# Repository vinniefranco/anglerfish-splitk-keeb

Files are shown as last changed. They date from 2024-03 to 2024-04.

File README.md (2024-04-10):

# Anglerfish Keyboard

Anglerfish, is a split keyboard with 3x5 column staggered keys, two thumb keys, and a trackpoint.

The Trackpoint can be placed on either side, and the PCB is a reversible design.

---

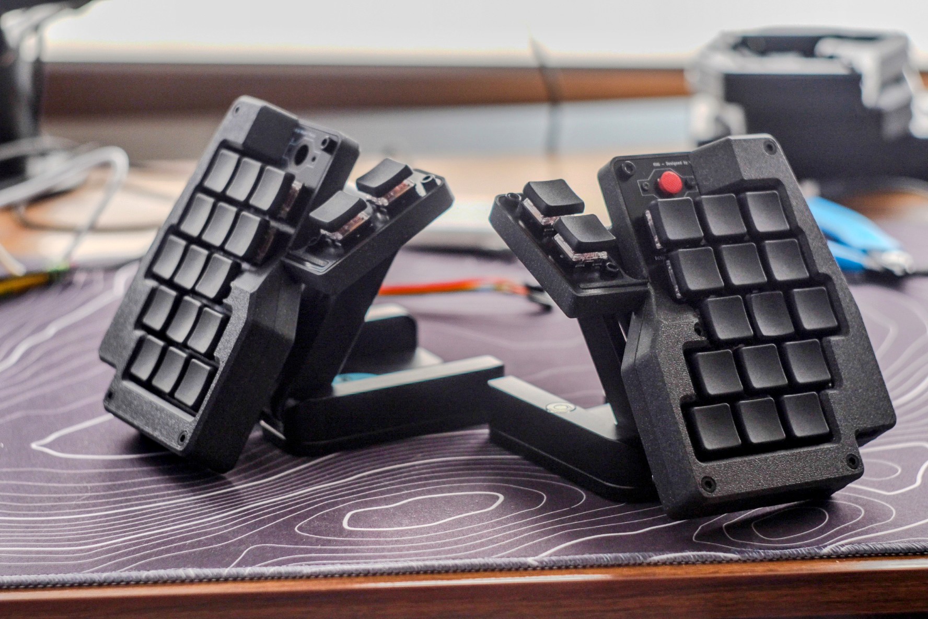
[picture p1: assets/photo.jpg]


---

### Models
You can find all the step files for the case [here](assets/models)

### Electronic Components 
[Build of materials](assets/bom.md)

### Default Firmware Keymap
Keymap

---

### Build Guide
Soon...

> [!NOTE]\
> IMPORTANT: When submitting the gerber for manufacturing, set the PCB thickness to 0.8mm.

> [!WARNING]\
>  Gotchas
> Trackpoint ZMK support is bleeding edge. Thar be dragons.

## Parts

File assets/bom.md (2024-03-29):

| Part name | Amount | Link
| --- | ---|  --- |
| M3 Brass Inserts | 20x | |
| 1/4" Brass Inserts | 2x |  |
| M3x10 Hex bolts | 4x | |
| M3x12 Hex bolts | 8x | |
| M3x6 Hex bolts | 6x | |
| M1.8 Torx bolts | 2x | [Aliexpress](https://www.aliexpress.us/item/3256802141626309.html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)  | 
| nice!nano or clone | 2x | [Aliexpress](https://www.aliexpress.us/item/3256805848952479.html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)
| Diodes - 1N4148W - SOD-123 | 32x | [Aliexpress](https://www.aliexpress.us/item/3256806388498396.html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)
| Reset Button - B35-1000 - SPST | 2x | [Aliexpress](https://www.aliexpress.us/item/2251832345840617.html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)
| Power Switch - PCM12 - SPDT | 2x | [Aliexpress](https://www.aliexpress.us/item/3256806061518634.html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)
| Kailh Choc Keyswitches | 32x | [Aliexpress](https://www.aliexpress.us/item/3256805260407528.html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)
| Red Trackpoint - T460P | 1x | Find out more info in #pointing-devices om ZMK discord |
| Trackpoint Connector - 12pin FPC Connector | 1x | [Aliexpress](https://www.aliexpress.us/item/3256802303960160.html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)
| Battery Connector - JST PH2.0 2pin Male | 2x | [Aliexpress](https://www.aliexpress.us/item/3256801477686458.html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)

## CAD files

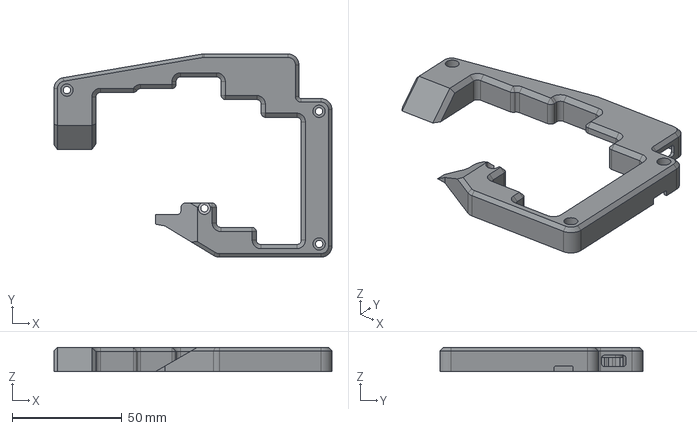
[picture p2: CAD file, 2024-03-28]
assets/models/anglerfish_v2_top_case.step
126.5 x 92.5 x 11.0 mm

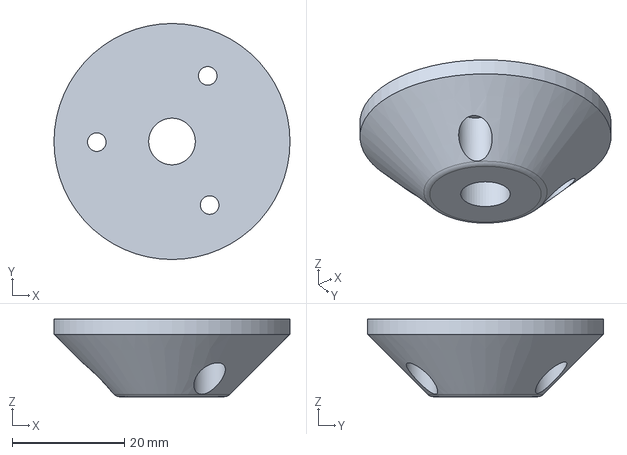
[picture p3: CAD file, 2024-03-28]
assets/models/anglerfish_v2_mount.step
42.0 x 42.0 x 13.8 mm

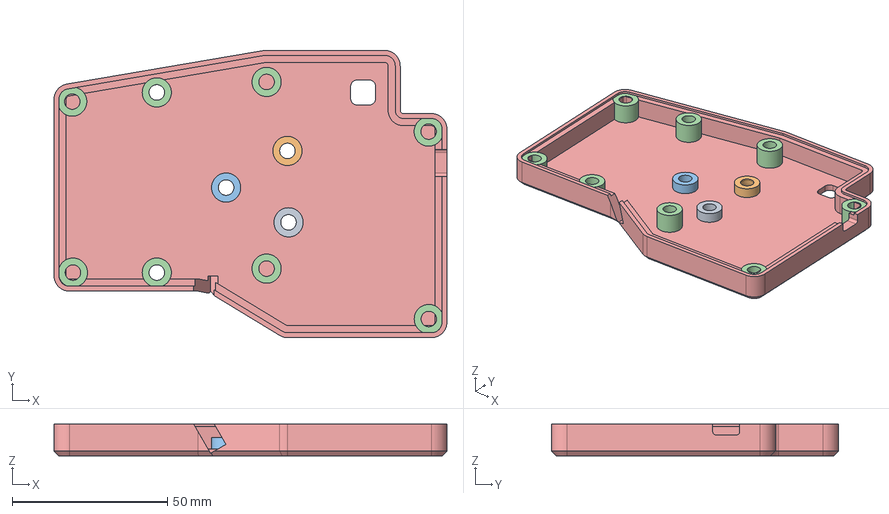
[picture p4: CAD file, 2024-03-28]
assets/models/anglerfish_v2_bottom_case.step
126.5 x 92.5 x 10.3 mm
Mount Attachment
Linear Pattern 03
Main Holes (1)

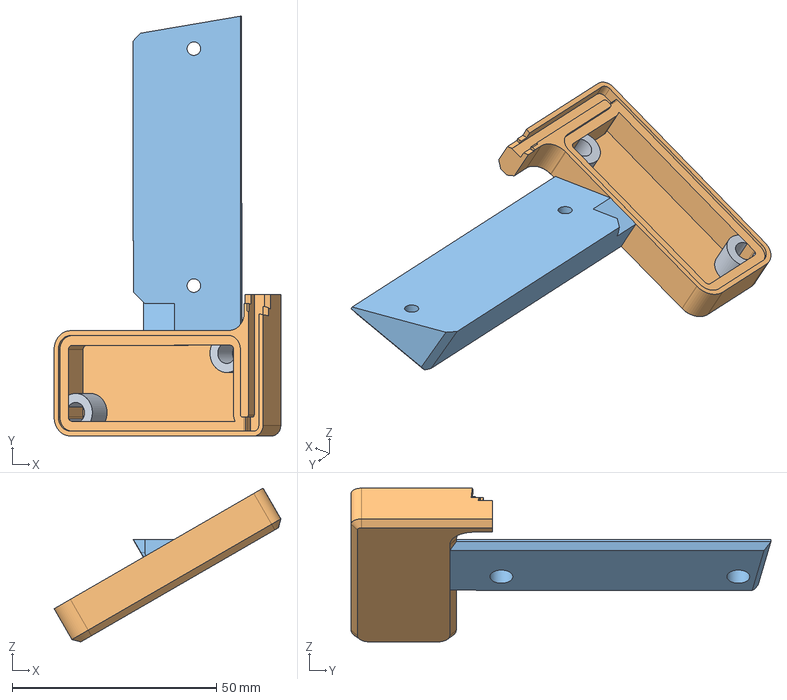
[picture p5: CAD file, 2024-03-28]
assets/models/anglerfish_v2_thumbcluster.step
55.5 x 102.8 x 37.7 mm

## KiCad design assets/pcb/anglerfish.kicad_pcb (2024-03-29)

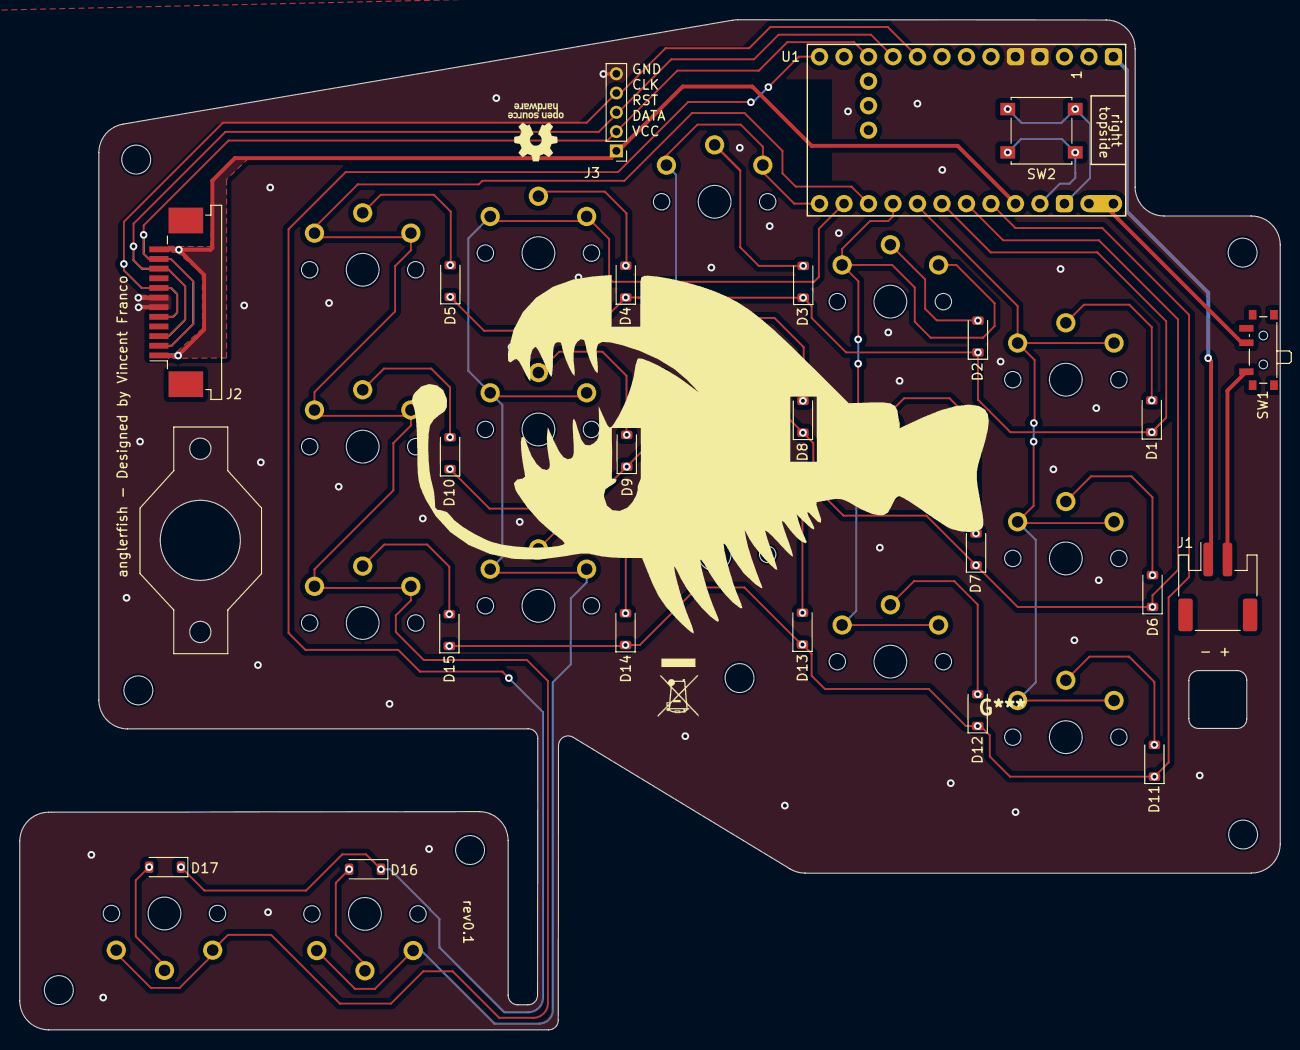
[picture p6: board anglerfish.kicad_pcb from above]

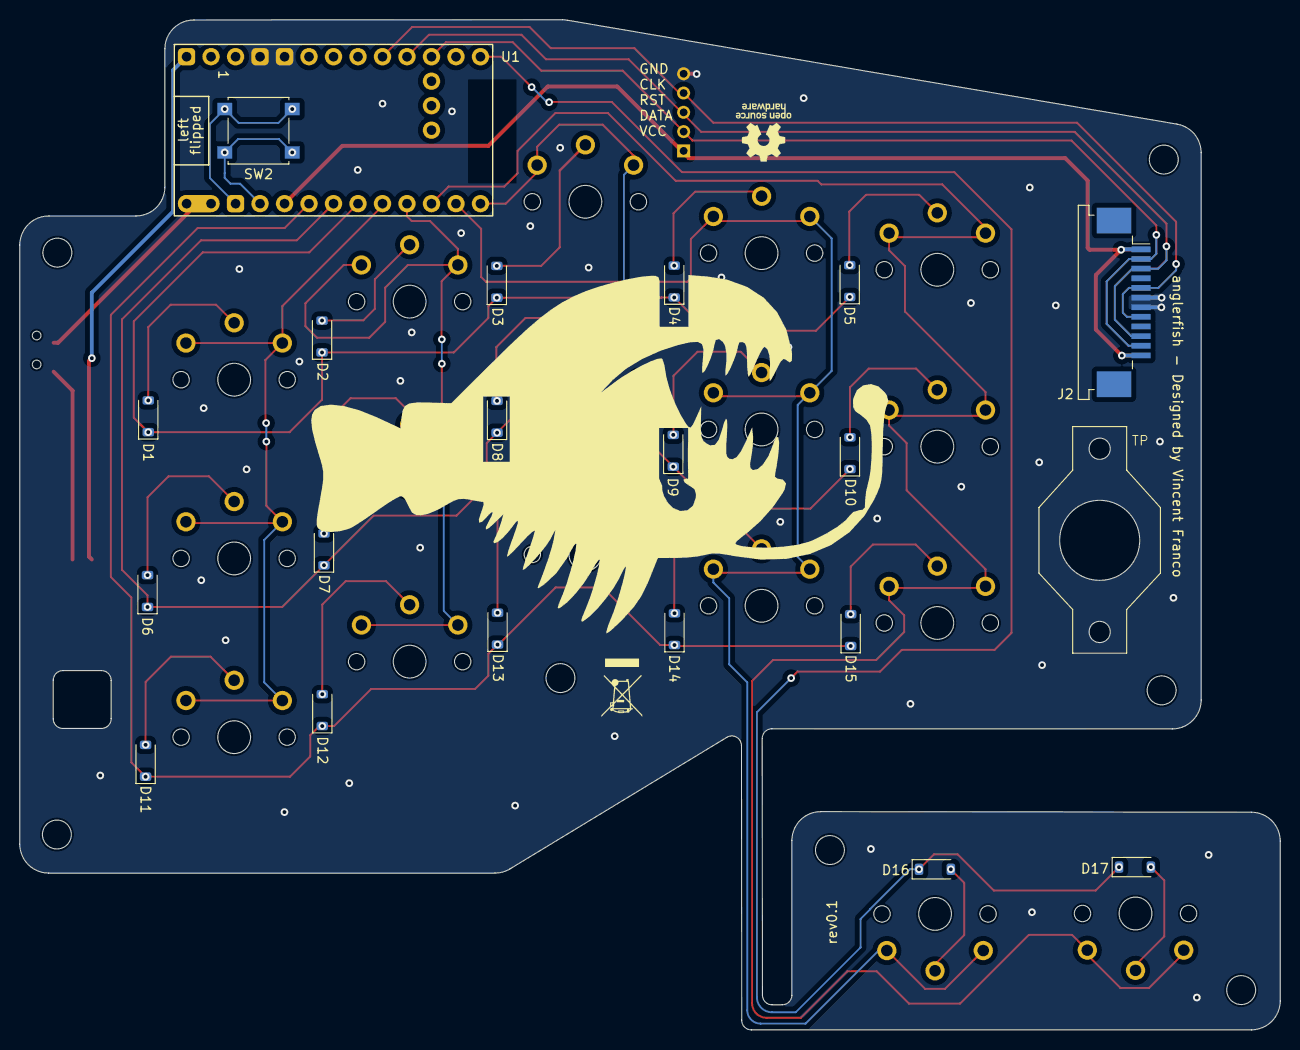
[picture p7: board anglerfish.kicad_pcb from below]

Board: 2 copper layers, 130.7 x 104.8 mm, 67 parts (19 on the bottom side), 35 nets.

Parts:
CH1, CH2, CH3, CH4, CH5, CH6, CH7, CH8, CH9, CH10, CH11, CH12, CH13, CH14, CH15, CH16, CH17: kailh choc; SW_choc_Reversible_1u
D1, D1#2, D2, D2#2, D3, D3#2, D4, D4#2, D5, D5#2, D6, D6#2, D7, D7#2, D8, D8#2, D9, D9#2, D10, D10#2, D11, D11#2, D12, D12#2, D13, D13#2, D14, D14#2, D15, D15#2, D16, D16#2, D17, D17#2: 1N4148; D_SOD-123
H1, H1#2, H2, H3, H4, H5, H6: MountingHole; MountingHole_3mm
J1: JST_PH_S2B-PH-SM4-TB; JST_PH_S2B-PH-SM4-TB_1x02-1MP_P2.00mm_Horizontal
J2, J2#2: TE_1-84952-2; TE_1-84952-2_1x12-1MP_P1.0mm_Horizontal
J3: Conn_01x05_Socket; PinHeader_1x05_P2.00mm_Vertical
SW1: SW_SPST_PCM12; SW_SPDT_PCM12
SW2, SW2#2: SW_SPST_B3S-1000
TP: Trackpoint
U1: supermini nrf / nice nano v2; nice_nano_AH_USBup

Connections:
BATTN: J1.1, U1.28 (GND)
BATTP: J1.2, SW1.1 (A), SW1.2 (B), U1.13 (BAT+), U1.29 (BAT+)
COL0: CH1.1, CH6.1, CH11.1, U1.20 (P1.15-LF)
COL1: CH2.1, CH7.1, CH12.1, U1.21 (P1.13-LF)
COL2: CH3.1, CH8.1, CH13.1, U1.24 (P0.09-LF)
COL3: CH4.1, CH9.1, CH14.1, CH16.1, U1.23 (P0-10-LF)
COL4: CH5.1, CH10.1, CH15.1, CH17.1, U1.22 (P1.11-LF)
unnamed: CH1.2, D1.2 (A), D1#2.2 (A)
unnamed: CH2.2, D2.2 (A), D2#2.2 (A)
unnamed: CH3.2, D3.2 (A), D3#2.2 (A)
unnamed: CH4.2, D4.2 (A), D4#2.2 (A)
unnamed: CH5.2, D5.2 (A), D5#2.2 (A)
unnamed: CH6.2, D6.2 (A), D6#2.2 (A)
unnamed: CH7.2, D7.2 (A), D7#2.2 (A)
unnamed: CH8.2, D8.2 (A), D8#2.2 (A)
unnamed: CH9.2, D9.2 (A), D9#2.2 (A)
unnamed: CH10.2, D10.2 (A), D10#2.2 (A)
unnamed: CH11.2, D11.2 (A), D11#2.2 (A)
unnamed: CH12.2, D12.2 (A), D12#2.2 (A)
unnamed: CH13.2, D13.2 (A), D13#2.2 (A)
unnamed: CH14.2, D14.2 (A), D14#2.2 (A)
unnamed: CH15.2, D15.2 (A), D15#2.2 (A)
unnamed: CH16.2, D16.2 (A), D16#2.2 (A)
unnamed: CH17.2, D17.2 (A), D17#2.2 (A)
ROW0: D1.1 (K), D1#2.1 (K), D2.1 (K), D2#2.1 (K), D3.1 (K), D3#2.1 (K), D4.1 (K), D4#2.1 (K), D5.1 (K), D5#2.1 (K), U1.19 (P0.02-LF)
ROW1: D6.1 (K), D6#2.1 (K), D7.1 (K), D7#2.1 (K), D8.1 (K), D8#2.1 (K), D9.1 (K), D9#2.1 (K), D10.1 (K), D10#2.1 (K), U1.18 (P0.29-LF)
ROW2: D11.1 (K), D11#2.1 (K), D12.1 (K), D12#2.1 (K), D13.1 (K), D13#2.1 (K), D14.1 (K), D14#2.1 (K), D15.1 (K), D15#2.1 (K), U1.17 (P0.31-LF)
ROW3: D16.1 (K), D16#2.1 (K), D17.1 (K), D17#2.1 (K), U1.12 (P1.06-LF)
RSTG: SW2.2 (B), SW2#2.2 (B), U1.14 (GND)
RSTR: SW2.1 (A), SW2#2.1 (A), U1.15 (RST)
TPCLK: J2.5, J2.8, J2#2.5, J2#2.8, J3.4, U1.8 (P0.24)
TPDATA: J2.2, J2.11, J2#2.2, J2#2.11, J3.2, U1.10 (P0.11)
TPGND: J2.6, J2.7, J2#2.6, J2#2.7, J3.5, U1.3 (GND), U1.4 (GND)
TPRST: J2.3, J2.10, J2#2.3, J2#2.10, J3.3, U1.9 (P1.00)
TPVCC: J2.1, J2.12, J2#2.1, J2#2.12, J3.1, U1.16 (3V3)

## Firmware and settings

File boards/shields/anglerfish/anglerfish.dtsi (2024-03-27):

#include <dt-bindings/zmk/matrix_transform.h>

/ {
  chosen {
    zmk,kscan = &kscan0;
    zmk,matrix_transform = &default_transform;
  };

  default_transform: keymap_transform_0 {
    compatible = "zmk,matrix-transform";
    columns = <10>;
    rows = <4>;

    map = <
      RC(0, 0) RC(0, 1) RC(0, 2) RC(0, 3) RC(0, 4)        RC(0, 5) RC(0, 6) RC(0, 7) RC(0, 8) RC(0, 9)
      RC(1, 0) RC(1, 1) RC(1, 2) RC(1, 3) RC(1, 4)        RC(1, 5) RC(1, 6) RC(1, 7) RC(1, 8) RC(1, 9)
      RC(2, 0) RC(2, 1) RC(2, 2) RC(2, 3) RC(2, 4)        RC(2, 5) RC(2, 6) RC(2, 7) RC(2, 8) RC(2, 9)
                                 RC(3, 3) RC(3, 4)        RC(3, 5) RC(3, 6)
    >;
  };

  kscan0: kscan_0 {
    compatible = "zmk,kscan-gpio-matrix";
    label = "KSCAN";

    diode-direction = "col2row";

    row-gpios = <&pro_micro 19 (GPIO_ACTIVE_HIGH | GPIO_PULL_DOWN)>,
                <&pro_micro 20 (GPIO_ACTIVE_HIGH | GPIO_PULL_DOWN)>,
                <&pro_micro 21 (GPIO_ACTIVE_HIGH | GPIO_PULL_DOWN)>,
                <&pro_micro 9 (GPIO_ACTIVE_HIGH | GPIO_PULL_DOWN)>;
  };

};
&pro_micro_i2c {
    status = "disabled";
};
/*
 * PS/2 Mouse / Trackpoint
 */

// Configure the SCL and SDA pins of the PS/2 mouse/tp using the `&pro_micro`
// notation.
//
// If possible, try to choose the blue high frequency pins to avoid
// bluetooth interference.
//
// On the nice!nano documentation these are green DX pins:
// https://nicekeyboards.com/docs/nice-nano/pinout-schematic
//
// Clock pin P0.24
#define MOUSE_PS2_PIN_SCL_PRO_MICRO <&pro_micro 5 GPIO_ACTIVE_HIGH>
// Data pin P0.11.
#define MOUSE_PS2_PIN_SDA_PRO_MICRO <&pro_micro 7 GPIO_ACTIVE_HIGH>


// Uncomment and configure this pin if you have an extra free pin and want the
// controller to perform the Power-On-Reset sequence, which many trackpoints
// require, instead of using a trackpoint reset circuit.
//
// It's ok to use a low-frequency pin for this.
#define MOUSE_PS2_PIN_RST_PRO_MICRO <&pro_micro 6 GPIO_ACTIVE_HIGH>


// Now configure the same SDA pin using the pinctrl notation.
//
// For that you have to use the PX.XX notation of the nrf52 chip.
//
// On the nice!nano pinout they are shown in blue and purple next to the green
// DX pin.
//
// Enter it like `X, Y` without leading zeroes.
// Examples:
// 		D0 - P0.08: 0, 8
//		D15 - P1.13: 1, 13
//
// We don't define the SCL pin, because UART uses a baud rate instead of
// a clock pin.
#define MOUSE_PS2_PIN_SDA_PINCTRL <NRF_PSEL(UART_RX, 0, 11)>


// In UART two different pins are used for receiving and transmitting, but PS/2
// uses the same pin for both.
//
// The UART config still requires both pins to be configured. So we use one of
// the nrf52 pins that are not exposed on the nice!nano board.
#define MOUSE_PS2_PIN_UNEXPOSED_TX <NRF_PSEL(UART_TX, 0, 27)>
#define MOUSE_PS2_PIN_UNEXPOSED_RX <NRF_PSEL(UART_RX, 0, 28)>


// The PS/2 GPIO driver
/ {
    gpio_ps2: gpio_ps2 {
		status = "disabled";
        compatible = "gpio-ps2";
        scl-gpios = MOUSE_PS2_PIN_SCL_PRO_MICRO;
        sda-gpios = MOUSE_PS2_PIN_SDA_PRO_MICRO;
    };
};


&pinctrl {
	// This pinctrl state is used for receiving
	// For `UART_TX`, set an unused and unexposed pin
	// For `UART_RX`, set the PS/2 SDA pin number
	uart0_ps2_default: uart0_ps2_default {
		group1 {
			psels = MOUSE_PS2_PIN_UNEXPOSED_TX,
					MOUSE_PS2_PIN_SDA_PINCTRL;
		};
	};

	// Set this to the same pins as uart0_ps2_default
	uart0_ps2_sleep: uart0_ps2_sleep {
		group1 {
			psels = MOUSE_PS2_PIN_UNEXPOSED_TX,
					MOUSE_PS2_PIN_SDA_PINCTRL;
			low-power-enable;
		};
	};

	// The nrf52 UART controller is not compatible with the PS/2
	// transmission frame. So we don't use UART for transmissions
	// and instead use GPIO bitbanging.
	//
	// When we switch to transmit mode, we free up the SDA pin by switching
	// UART to unexposed/unused pins.
	//
	// Then we can configure the pins to be used with the GPIO controller.
	uart0_ps2_off: uart0_ps2_off {
		group1 {
			psels = MOUSE_PS2_PIN_UNEXPOSED_TX,
					MOUSE_PS2_PIN_UNEXPOSED_RX;
		};
	};
};
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

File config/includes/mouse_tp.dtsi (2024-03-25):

#ifdef HAS_MOUSE_TP
  #include <dt-bindings/zmk/mouse_settings.h>
  #include <behaviors/mouse_setting.dtsi>

 /*
  * Key Behaviors to adjust settings
  */

  // They key codes below can be used to adjust the TP settings at runtime
  // without needing to recompile the firmware.
  //
  // The values will be logged and saved in the config on the controller flash
  // after 60s (CONFIG_ZMK_SETTINGS_SAVE_DEBOUNCE).
  //
  // On boot the settings will be restored again.
  //
  // If you prefer a more explicit way of configuration, you can also hardcode
  // these settings in `&mouse_ps2`.
  //
  // If you set these settings in `&mouse_ps2`, you will still be able to
  // adjust the values during runtime with these key codes, but after
  // restarting the board the values in `&mouse_ps2` will be restored and not
  // the ones stored in the flash using the key codes.


  // How sensitive the trackpoint is
  #define U_MSS_TP_S_I &mms MS_TP_SENSITIVITY_INCR
  #define U_MSS_TP_S_D &mms MS_TP_SENSITIVITY_DECR


  // The maximum speed the trackpoint will accelerate to
  #define U_MSS_TP_V6_I &mms MS_TP_VALUE6_INCR
  #define U_MSS_TP_V6_D &mms MS_TP_VALUE6_DECR


  // I am not quite sure tbh... default seems fine.
  #define U_MSS_TP_NI_I &mms MS_TP_NEG_INERTIA_INCR
  #define U_MSS_TP_NI_D &mms MS_TP_NEG_INERTIA_DECR


  // How hard you have to press to activate the "Press To Select" feature that
  // lets you tap or press on the trackpoint to click.
  //
  // Not all trackpoints support it and you have to enable
  // `tp-press-to-select;` in `&mouse_ps2` first.
  #define U_MSS_TP_PT_I &mms MS_TP_PTS_THRESHOLD_INCR
  #define U_MSS_TP_PT_D &mms MS_TP_PTS_THRESHOLD_DECR


  // If you mess up the settings, you can use this key code to clear the
  // settings from flash and re-set the default values on the TP.
  //
  // Make sure to wait at least CONFIG_ZMK_SETTINGS_SAVE_DEBOUNCE seconds (60
  // by default) before restarting the board to ensure the settings are
  // written to flash storage.
  #define U_MSS_RESET   &mms MS_RESET


  // If you prefer to set the settings in `&mouse_ps2`, you can use the key
  // codes above to find the settings you like the most and then press this
  // key code to output the settings to the log.
  //
  // Then you can add those values to `&mouse_ps2`
  #define U_MSS_LOG     &mms MS_LOG


 /*
  * Driver-specific configuration
  */

  &mouse_ps2 {
    // Enables scroll wheel on mouse devices supporting the Intellimouse
    // extension.
    // scroll-mode;


    // Disables clicking. Useful when using a PS2 driver that is prone to
    // erros in transmissions to reduce accidental clicks.
    // disable-clicking;

    // The frequency at which the mouse samples and sends data (in hz).
    // The default rate is 100. You can try lowering it if you experience
    // connection errors.
    //
    // Higher values than 100 are no improvement in my experience, but will
    // increase battery life and potentially errors in transmissions.
    //
    // These values are allowed: 10,20,40,60,80,100,200
    // sampling-rate = <60>;


    // Enable clicking by tapping on the TP. Not all TPs support this.
    // tp-press-to-select;
    // tp-press-to-select-threshold = <10>;


    // How sensitive the TP is (Default: 128)
    tp-sensitivity = <135>;


    // The maximum mouse movement speed the TP will accelarate to (Default: 97)
    tp-val6-upper-speed = <182>;


    // Not quite sure what it does tbh :) (Default: 6)
    tp-neg-inertia = <6>;


    // Adjusts axis settings on the TP
    // Works only on some trackpoints, but may be properly considered by the
    // trackpoint's acceleration features (which may or may not have an
    // impact). Alternatively consider achieving the same effect using the
    //  `zmk,input-configs` feature.
    // tp-xy-swap;
    // tp-x-invert;
    // tp-y-invert;

  };

 /*
  * Input Config
  */

  &mouse_ps2_input_listener {
    xy-swap;
    x-invert;
    y-invert;

    // Set the layer that should automatically activate when the mouse is
    // moving.
    layer-toggle = <VNAVI>;

    // How long the mouse needs to move for before the layer is activated (to
    // avoid accidental activations while typing) (Default: 250)
    layer-toggle-delay-ms = <250>;

    // How long to wait, after the last mouse movement, before deactivating
    // the layer (Default: 250)
    layer-toggle-timeout-ms = <250>;
  };


#endif

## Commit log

2024-03-25 try enabling reset pin
2024-03-28 Adding models
    [anglerfish_v2_bottom_case.step, anglerfish_v2_mount.step, anglerfish_v2_thumbcluster.step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]
